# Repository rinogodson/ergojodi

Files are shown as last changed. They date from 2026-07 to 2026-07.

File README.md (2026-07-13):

ergojodi logo

---
### Fully custom hot-swappable split mechanical keyboard that features a very ergonomic layout and uses USB-C for everything, way better than accident-friendly TRRS. Runs on QMK software, controlling key functions. The fully assembled keyboard's 3D Model's STEP file is over 100MB, So, you can find the drive link in `assembly.md`
The name comes from two words, "Ergo" meaning Ergonomics, and "Jodi" meaning pair.

> **Why I built this**: I needed an ergonomic keyboard to use with my machines that suits my ergonomics. I aligned and laid out the keys to match my finger heights.

gray_run_8fps

ergojodi assembled

---

### Schematic
Ergogen keebs doesn't need a schematic, because it is in ergogen... But, for your sake, I made one!

Schematic

---
### PCB
Designed in Ergogen and Routed in KiCad

PCB

3D PCB

---
## Case  
Case designed with ergogen. It comes in two parts: the top plate and bottom case. The M2 Screw holes are already present, and heat inserts should be added to the top plate.

case

---
## Firmware  
This Keyboard runs on QMK software; the uf2 file to flash can be found in `firmware/uf2`.  

## Parts List and Links:
| Name | Price (USD) | Quantity | Link | Total (USD) | Delivery and Tax | Shop Total (USD) |
| :--- | :--- | :--- | :--- | :--- | :--- | :--- |
| Outemu Mechanical Switches for Swappable Keyboards (Pack of 20) | $2.30 | 2 | [Visit Shop](https://www.thecosmicbyte.com/product/outemu-mechanical-switches-for-swappable-keyboards-pack-of-20/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) | $4.60 | $0.87 | $5.46 |
| Gateron Hotswap Sockets | $0.10 | 40 | [Visit Shop](https://stackskb.com/store/gateron-hotswap-sockets/) | $4.18 | $1.36 | $5.54 |
| Blank DSA Keycaps (1u) (5n per order) | $0.99 | 8 | [Visit Shop](https://meckeys.com/shop/accessories/keyboard-accessories/keycaps/blank/blank-dsa-keycaps-1u/) | $7.94 | $1.04 | $8.98 |
| TYPE-C-31-M-12-Hroparts-5A 1 16P Female Type-C SMD USB Connectors ROHS | $0.40 | 2 | [Visit Shop](https://robu.in/product/type-c-31-m-12-hroparts-5a-1-16p-female-type-c-smd-usb-connectors-rohs/) | $0.79 | Free | $14.33 |
| Seeed Studio XIAO RP2040 v1.0 | $6.46 | 2 | [Visit Shop](https://robu.in/product/seeed-studio-xiao-rp2040-v1-0/) | $12.91 | | |
| 1N4148-T50A-Onsemi-100V 1V@10mA 4ns 200mA DO-35 Switching Diodes ROHS | $0.06 | 10 | [Visit Shop](https://robu.in/product/1n4148-t50a-onsemi-100v-1v10ma-4ns-200ma-do-35-switching-diodes-rohs/) | $0.63 | | |
| M2 X 3mm Brass Threaded Inserts (Dia. 2mm, Length 3mm) | $0.02 | 15 | [Visit Shop](https://onlyscrews.in/products/m2-x-3mm-brass-threaded-inserts?variant=49728872448313) | $0.28 | $0.73 | $1.70 |
| M2 X 8mm Phillips Round head Laptop Screw (Dia. 2mm, Length 8mm) | $0.05 | 15 | [Visit Shop](https://onlyscrews.in/products/m2-x-8mm-phillips-round-head-laptop-screw-1?variant=49693360423225) | $0.69 | | |
| PCB Manufacturing & Shipping (JLCPCB) | $26.17 | 1 | [Visit Shop](https://jlcpcb.com/) | $26.17 | - | $26.17 |
| 3D Printing & Shipping (3Ding) | $11.43 | 1 | [Visit Shop](https://3ding.in/) | $11.43 | - | $11.43 |

### Total ~ $74

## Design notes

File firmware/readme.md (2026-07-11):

# ergojodi

ergojodi

*A short description of the keyboard/project*

* Keyboard Maintainer: [Rino Godson](https://github.com/rinogodson)
* Hardware Supported: *The PCBs, controllers supported*
* Hardware Availability: *Links to where you can find this hardware*

Make example for this keyboard (after setting up your build environment):

    make ergojodi:default

Flashing example for this keyboard:

    make ergojodi:default:flash

See the [build environment setup](https://docs.qmk.fm/#/getting_started_build_tools) and the [make instructions](https://docs.qmk.fm/#/getting_started_make_guide) for more information. Brand new to QMK? Start with our [Complete Newbs Guide](https://docs.qmk.fm/#/newbs).

## Bootloader

Enter the bootloader in 3 ways:

* **Bootmagic reset**: Hold down the key at (0,0) in the matrix (usually the top left key or Escape) and plug in the keyboard
* **Physical reset button**: Briefly press the button on the back of the PCB - some may have pads you must short instead
* **Keycode in layout**: Press the key mapped to `QK_BOOT` if it is available

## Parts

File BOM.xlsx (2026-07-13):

Name | Price | Quantity | Link | Total | Delivery and Tax | Shop Total
Outemu Mechanical Switches for Swappable Keyboards (Pack of 20) | ₹220.00 | 2 | https://www.thecosmicbyte.com/product/outemu-mechanical-switches-for-swappable-keyboards-pack-of-20/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 | ₹440.00 | ₹83.00 | ₹523.00
Gateron Hotswap Sockets | ₹10.00 | 40 | https://stackskb.com/store/gateron-hotswap-sockets/ | ₹400.00 | ₹130.00 | ₹530.00
Blank DSA Keycaps (1u) (5n per order) | ₹95.00 | 8 | https://meckeys.com/shop/accessories/keyboard-accessories/keycaps/blank/blank-dsa-keycaps-1u/ | ₹760.00 | ₹100.00 | ₹860.00
TYPE-C-31-M-12-Hroparts-5A 1 16P Female Type-C SMD USB Connectors ROHS | ₹38.00 | 2 | https://robu.in/product/type-c-31-m-12-hroparts-5a-1-16p-female-type-c-smd-usb-connectors-rohs/ | ₹76.00 | Free | ₹1372.00
Seeed Studio XIAO RP2040 v1.0 | ₹618.00 | 2 | https://robu.in/product/seeed-studio-xiao-rp2040-v1-0/ | ₹1236.00
1N4148-T50A-Onsemi-100V 1V@10mA 4ns 200mA DO-35 Switching Diodes ROHS | ₹6.00 | 10 | https://robu.in/product/1n4148-t50a-onsemi-100v-1v10ma-4ns-200ma-do-35-switching-diodes-rohs/ | ₹60.00
M2 X 3mm Brass Threaded Inserts (Dia. 2mm, Length 3mm) | ₹1.80 | 15 | https://onlyscrews.in/products/m2-x-3mm-brass-threaded-inserts?variant=49728872448313 | ₹27.00 | ₹70.00 | ₹163.00
M2 X 8mm Phillips Round head Laptop Screw (Dia. 2mm, Length 8mm) | ₹4.40 | 15 | https://onlyscrews.in/products/m2-x-8mm-phillips-round-head-laptop-screw-1?variant=49693360423225 | ₹66.00
PCB Manufacturing & Shipping (JLCPCB) | $26.17 | 1 | https://jlcpcb.com/ | $26.17 | - | $26.17
3D Printing & Shipping (3Ding) | ₹1094.00 | 1 | https://3ding.in/ | ₹1094.00 | - | ₹1094.00
 |  |  |  |  | Total (USD): | $73.62
 |  |  |  |  | Total (INR): | ₹ 7,046.70

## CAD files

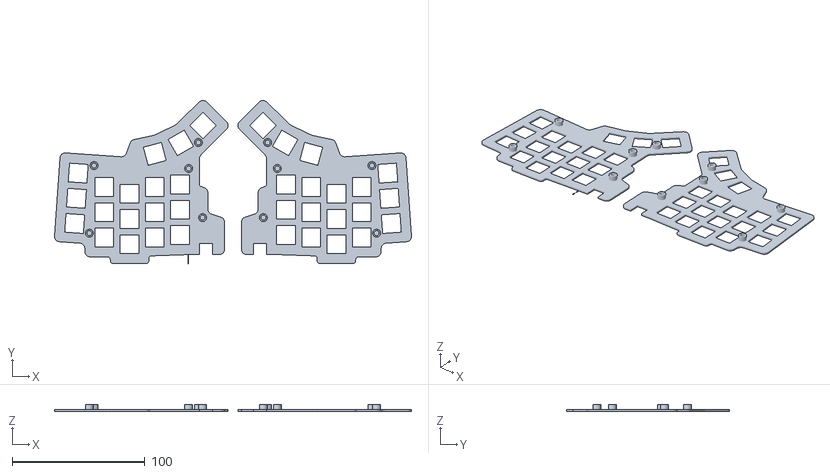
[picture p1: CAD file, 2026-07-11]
cases/top_new.stl
268.6 x 122.7 x 5.10

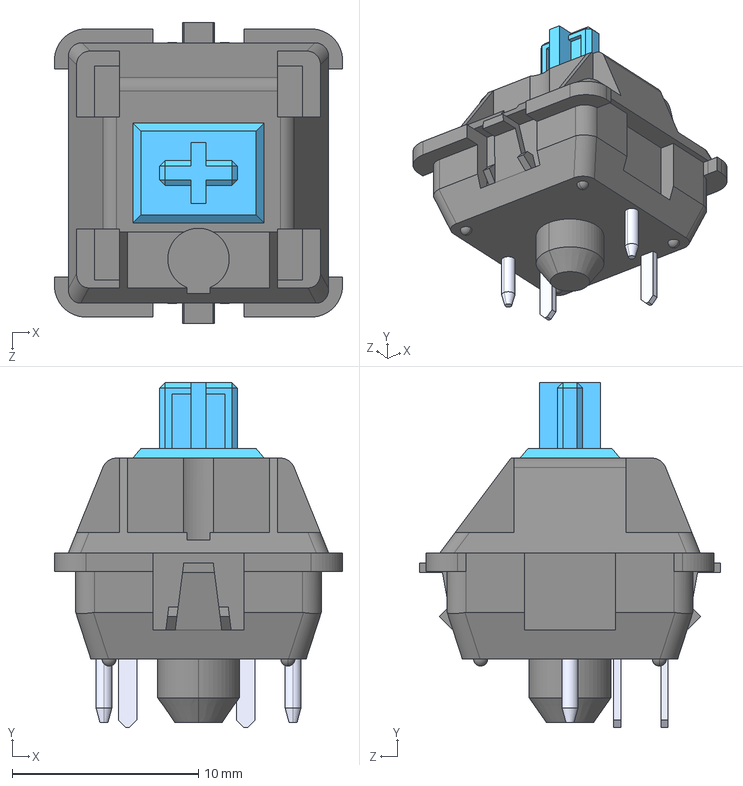
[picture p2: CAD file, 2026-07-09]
pcbs/models/mx.step
15.5 x 18.5 x 16.2 mm

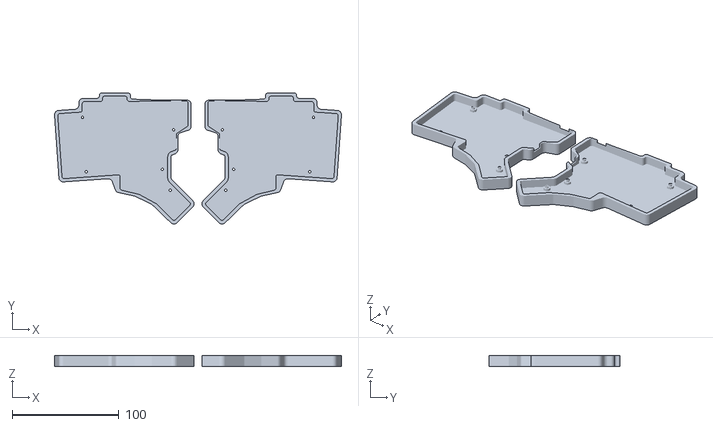
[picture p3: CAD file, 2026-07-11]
cases/bottom_new.stl
268.6 x 122.7 x 10.2

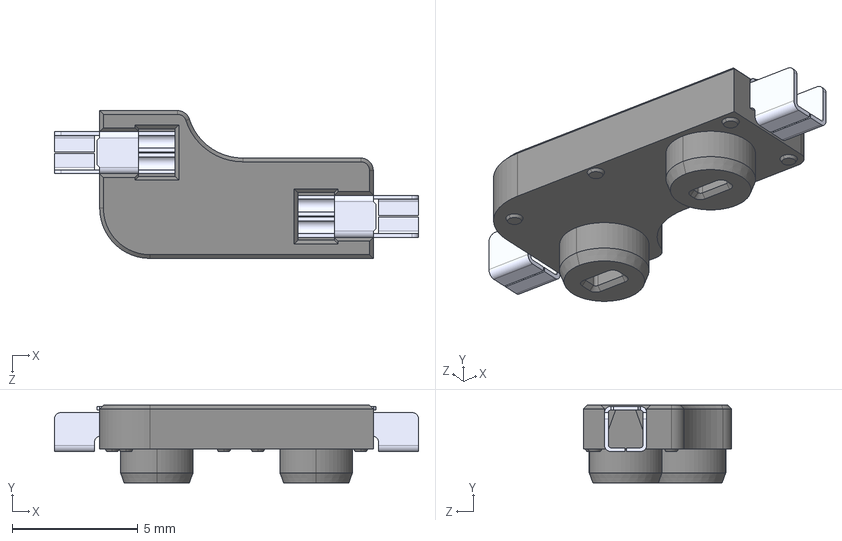
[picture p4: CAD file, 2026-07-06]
pcbs/models/kailh.step
14.5 x 3.10 x 5.89 mm

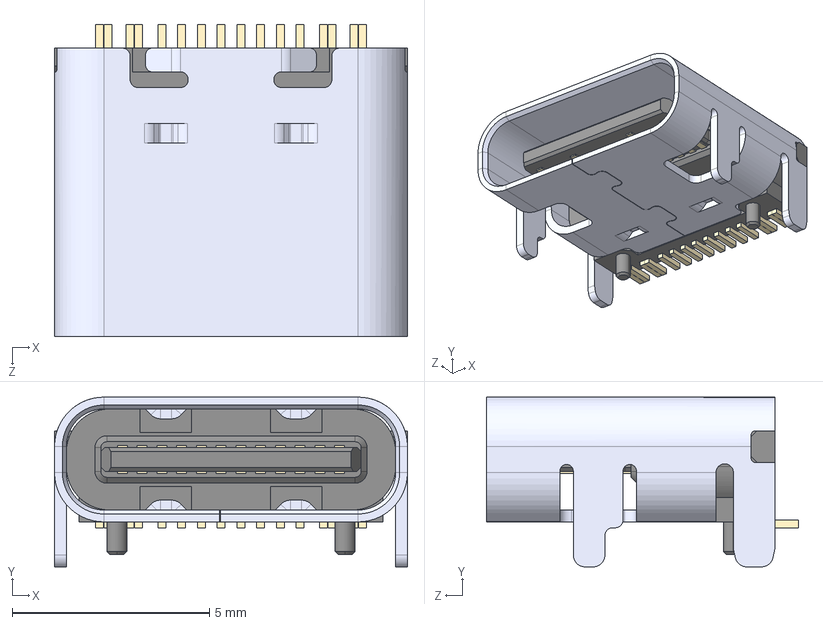
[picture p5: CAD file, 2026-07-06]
pcbs/models/usb.step
8.94 x 4.30 x 7.90 mm

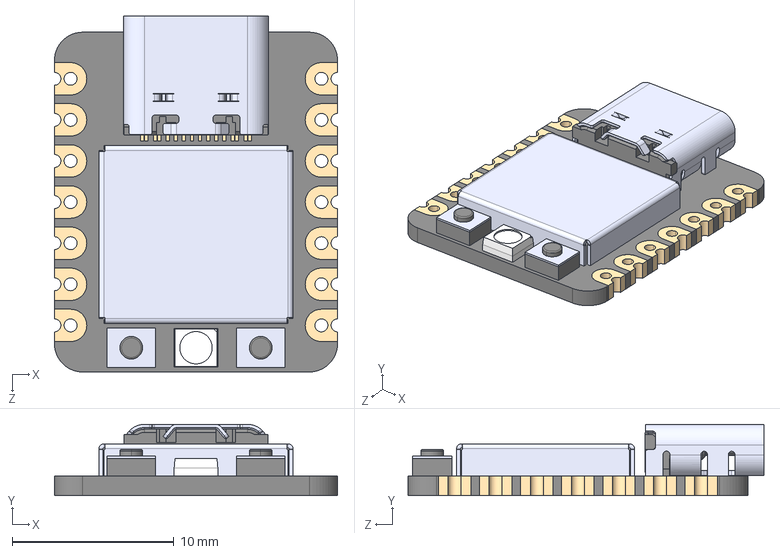
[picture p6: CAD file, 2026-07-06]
pcbs/models/xiao.step
17.5 x 4.40 x 22.0 mm

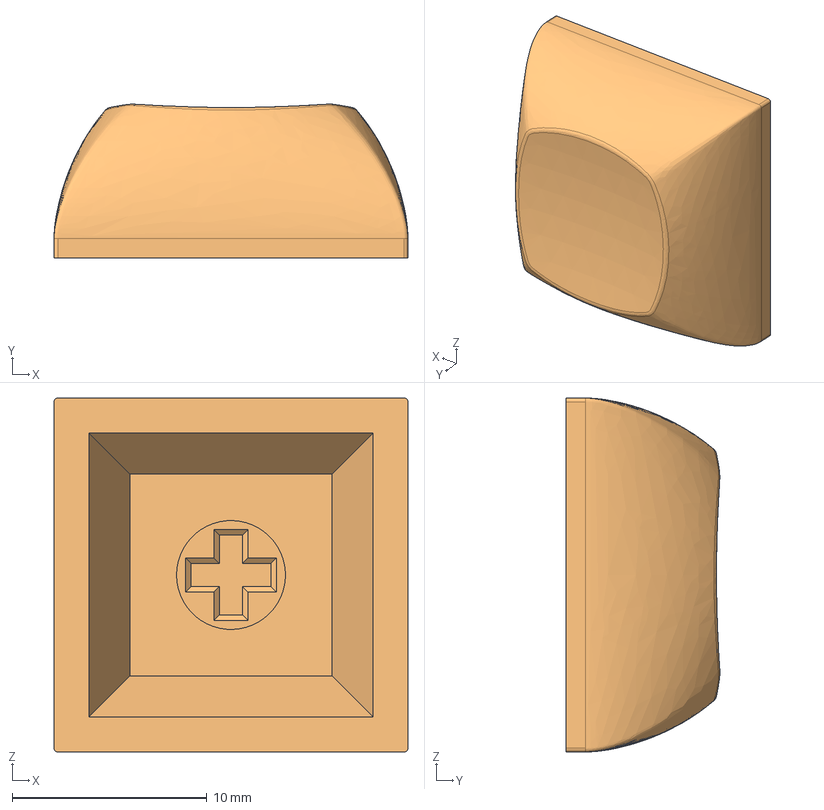
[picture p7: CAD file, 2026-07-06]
pcbs/models/dsa.step
18.2 x 7.91 x 18.2 mm

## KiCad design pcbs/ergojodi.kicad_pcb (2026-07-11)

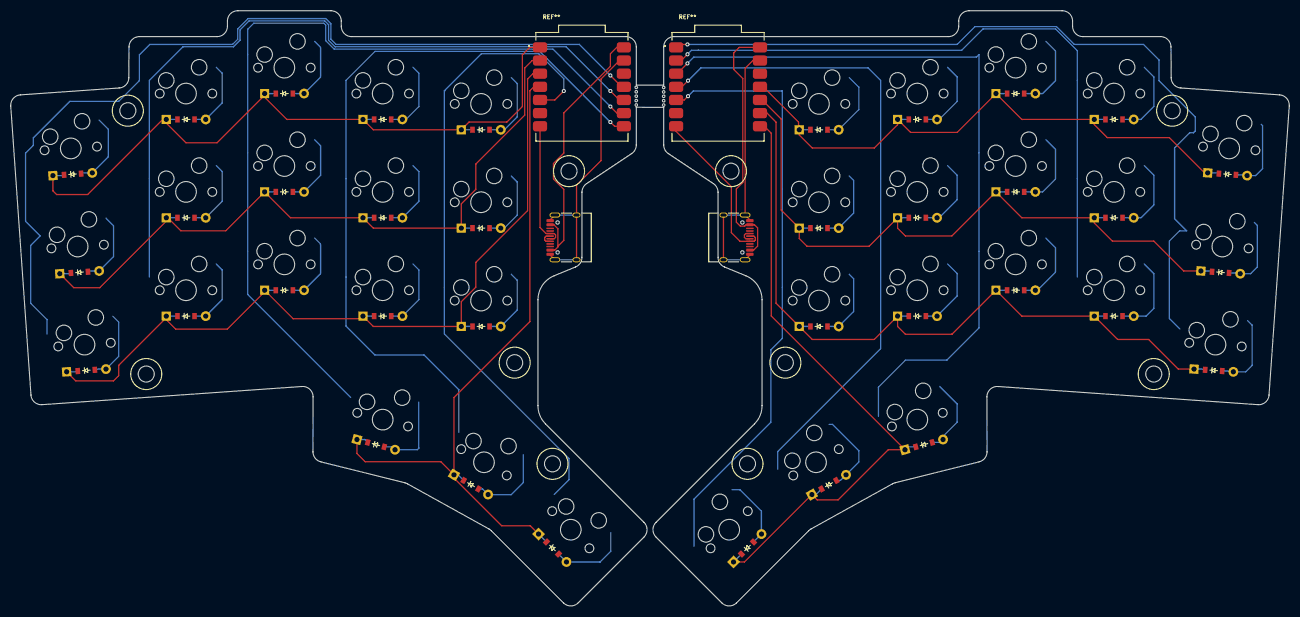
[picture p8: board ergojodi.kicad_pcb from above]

Board: 2 copper layers, 247.0 x 115.0 mm, 74 parts (0 on the bottom side), 62 nets.

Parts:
D1, D2, D3, D4, D5, D6, D7, D8, D9, D10, D11, D12, D13, D14, D15, D16, D17, D18, D19, D20, D21, D22, D23, D24, D25, D26, D27, D28, D29, D30, D31, D32, D33, D34, D35, D36: ComboDiode
S1, S2, S3, S4, S5, S6, S7, S8, S9, S10, S11, S12, S13, S14, S15, S16, S17, S18, S19, S20, S21, S22, S23, S24, S25, S26, S27, S28, S29, S30, S31, S32, S33, S34, S35, S36: MX
XX2, XX3: USB_C_Receptacle_HRO_TYPE-C-31-M-12

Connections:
far_thumb: D18.2, S18.2
home_thumb: D17.2, S17.2
index_bottom: D10.2, S10.2
index_home: D11.2, S11.2
index_top: D12.2, S12.2
inner_bottom: D13.2, S13.2
inner_home: D14.2, S14.2
inner_top: D15.2, S15.2
l_A0: D3.1, D6.1, D9.1, D12.1, D15.1
l_A1: D2.1, D5.1, D8.1, D11.1, D14.1
l_A2: D1.1, D4.1, D7.1, D10.1, D13.1
l_A3: D16.1, D17.1, D18.1
l_A4: S13.1, S14.1, S15.1, S18.1
l_A7: S10.1, S11.1, S12.1, S17.1
l_A8: S7.1, S8.1, S9.1, S16.1
l_A9: S4.1, S5.1, S6.1
l_A10: S1.1, S2.1, S3.1
l_Dminus: XX2.A7, XX2.B7
l_Dplus: XX2.A6, XX2.B6
l_GND: XX2.A1, XX2.A12, XX2.B1, XX2.B12, XX2.NP
l_VCC: XX2.A4, XX2.A9, XX2.B4, XX2.B9
middle_bottom: D7.2, S7.2
middle_home: D8.2, S8.2
middle_top: D9.2, S9.2
mirror_far_thumb: D36.2, S36.2
mirror_home_thumb: D35.2, S35.2
mirror_index_bottom: D28.2, S28.2
mirror_index_home: D29.2, S29.2
mirror_index_top: D30.2, S30.2
mirror_inner_bottom: D31.2, S31.2
mirror_inner_home: D32.2, S32.2
mirror_inner_top: D33.2, S33.2
mirror_middle_bottom: D25.2, S25.2
mirror_middle_home: D26.2, S26.2
mirror_middle_top: D27.2, S27.2
mirror_near_thumb: D34.2, S34.2
mirror_pinky_bottom: D19.2, S19.2
mirror_pinky_home: D20.2, S20.2
mirror_pinky_top: D21.2, S21.2
mirror_ring_bottom: D22.2, S22.2
mirror_ring_home: D23.2, S23.2
mirror_ring_top: D24.2, S24.2
near_thumb: D16.2, S16.2
pinky_bottom: D1.2, S1.2
pinky_home: D2.2, S2.2
pinky_top: D3.2, S3.2
r_A0: S19.1, S20.1, S21.1
r_A1: S22.1, S23.1, S24.1
r_A2: S25.1, S26.1, S27.1, S34.1
r_A3: S28.1, S29.1, S30.1, S35.1
r_A4: S31.1, S32.1, S33.1, S36.1
r_A7: D34.1, D35.1, D36.1
r_A8: D19.1, D22.1, D25.1, D28.1, D31.1
r_A9: D20.1, D23.1, D26.1, D29.1, D32.1
r_A10: D21.1, D24.1, D27.1, D30.1, D33.1
r_Dminus: XX3.A7, XX3.B7
r_Dplus: XX3.A6, XX3.B6
r_GND: XX3.A1, XX3.A12, XX3.B1, XX3.B12, XX3.NP
r_VCC: XX3.A4, XX3.A9, XX3.B4, XX3.B9
ring_bottom: D4.2, S4.2
ring_home: D5.2, S5.2
ring_top: D6.2, S6.2

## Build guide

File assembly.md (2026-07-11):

The Assembly 3D file is available on this link (can't push to github as it is 116MB):
https://drive.google.com/file/d/1jncvAFzqwWMEMiQR0Tw-UXtgj0F9NIJO/view?usp=sharing

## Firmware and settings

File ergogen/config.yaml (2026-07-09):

units:
  mcu_w: 15
  mcu_h: 20
  mcu_p: 2

  m2_ext: 6/2
  m2_ext_height: 2
  m2_ext_hole: 2.3/2
  m2_recess: 1.5
  m2_recess_radius: 4.5/2
  m2_boss: 3/2
  m2_boss_height: 1.4
  m2_hol: ((m2_boss*2)+0.1)/2

  m2_heat: 3.9/2
  m2_depth: 4

  # trrs_w: 13
  # (3-1.8)+2+1.6+4
  wall_thick_original: 3
  wall_thick: wall_thick_original*2
  pcb_thick: 1.6
  p: u+3
  p_in: p+1
  p_outer: p_in+wall_thick
  top_thick: 1.4
  x_height: wall_thick_original+m2_ext_height+pcb_thick+5-top_thick # 3+3+1.6+5-1.4
  k: 14
  k_t: k+0.075

points:
  zones:
    matrix:
      rows:
        bottom:
          # ROW3
          row_net: l_A2
          mirror.row_net: r_A8
        home:
          # ROW2
          row_net: l_A1
          mirror.row_net: r_A9
        top:
          # ROW1
          row_net: l_A0
          mirror.row_net: r_A10
      columns:
        pinky:
          # COL1
          key:
            column_net: l_A10
            mirror.column_net: r_A0
        ring:
          # COL2
          key:
            column_net: l_A9
            mirror.column_net: r_A1
            origin: [-12, -u]
            stagger: 10
            splay: -4
        middle:
          # COL3
          key:
            column_net: l_A8
            mirror.column_net: r_A2
            stagger: 5
        index:
          # COL4
          key:
            column_net: l_A7
            mirror.column_net: r_A3
            stagger: -5
        inner:
          # COL5
          key:
            column_net: l_A4
            mirror.column_net: r_A4
            stagger: -2
      anchor:
        shift: [100, -150]
        rotate: 4
    thumbfan:
      anchor:
        ref: matrix_index_bottom
        shift: [0, -25]
        rotate: -15
      columns:
        near:
          #COL3
          key:
            column_net: l_A8
            mirror.column_net: r_A2
        home:
          #COL4
          key:
            column_net: l_A7
            mirror.column_net: r_A3
            spread: U
            splay: -15
            origin: [-10, -9]
        far:
          #COL5
          key:
            column_net: l_A4
            mirror.column_net: r_A4
            spread: U
            splay: -15
            origin: [-10, -9]
      rows:
        thumb:
          #ROW4
          row_net: l_A3
          mirror.row_net: r_A7
  rotate: 0
  mirror: &mirror
    ref: thumbfan_far_thumb
    distance: 45
outlines:
  usb_cutout:
    - what: rectangle
      size: [9.5, 4]
      operation: add
      where:
        ref: matrix_inner_home
        shift: [20, -3.4mcu_p]
        rotate: 90
    - what: rectangle
      size: [9.5, 4]
      operation: add
      where:
        ref: mirror_matrix_inner_home
        shift: [20, -3.4mcu_p]
        rotate: 90
  keys:
    - what: rectangle
      where: true
      size: [k, k]
  keys_cutout:
    - what: rectangle
      where: true
      size: [k_t, k_t]
  m2_silk:
    - what: circle
      where:
        ref: matrix_pinky_top
        shift: [0.5p+0.5, 0.5p-4.5]
        rotate: 0
      radius: m2_ext
      operation: add
    - what: circle
      where:
        ref: matrix_pinky_bottom
        shift: [0.5p+0.5, -0.5p+4.5]
        rotate: 0
      radius: m2_ext
      operation: add
    - what: circle
      where:
        ref: matrix_inner_bottom
        shift: [0.5p-4.5, -0.5p-1]
        rotate: 0
      radius: m2_ext
      operation: add
    - what: circle
      where:
        ref: matrix_inner_home
        shift: [0.5p+6, 0.5p-5]
        rotate: 0
      radius: m2_ext
      operation: add
    - what: circle
      where:
        ref: thumbfan_far_thumb
        shift: [-0.5p-0.5, 0.5p-4.5]
        rotate: 0
      radius: m2_ext
      operation: add
      # right
    - what: circle
      where:
        ref: mirror_matrix_pinky_top
        shift: [0.5p+0.5, 0.5p-4.5]
        rotate: 0
      radius: m2_ext
      operation: add
    - what: circle
      where:
        ref: mirror_matrix_pinky_bottom
        shift: [0.5p+0.5, -0.5p+4.5]
        rotate: 0
      radius: m2_ext
      operation: add
    - what: circle
      where:
        ref: mirror_matrix_inner_bottom
        shift: [0.5p-4.5, -0.5p-1]
        rotate: 0
      radius: m2_ext
      operation: add
    - what: circle
      where:
        ref: mirror_matrix_inner_home
        shift: [0.5p+6, 0.5p-5]
        rotate: 0
      radius: m2_ext
      operation: add
    - what: circle
      where:
        ref: mirror_thumbfan_far_thumb
        shift: [-0.5p-0.5, 0.5p-4.5]
        rotate: 0
      radius: m2_ext
      operation: add
  m2_top_hole:
    - what: circle
      where:
        ref: matrix_pinky_top
        shift: [0.5p+0.5, 0.5p-4.5]
        rotate: 0
      radius: m2_heat
      operation: add
    - what: circle
      where:
        ref: matrix_pinky_bottom
        shift: [0.5p+0.5, -0.5p+4.5]
        rotate: 0
      radius: m2_heat
      operation: add
    - what: circle
      where:
        ref: matrix_inner_bottom
        shift: [0.5p-4.5, -0.5p-1]
        rotate: 0
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

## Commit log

2026-07-04 initialized PCB and better and more compact layout...
2026-07-06 added 3D models and added screws, and tried to make the case
    [dsa.step, kailh.step, mx.step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]
2026-07-07 m2 sizes added, making case
    [caseoriginal.jscad.stl]
2026-07-07 made the case, now need to copy all over to the left side
2026-07-09 made the entire case, top plate screw holes, and USB cutouts
    [caseoriginal.jscad.stl]
2026-07-09 pcb files add
    [dsa.step, ergojodi.kicad_pcb, kailh.step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]
2026-07-11 Routed the PCB
    [ergojodi.kicad_pcb]
2026-07-11 added gerber files
2026-07-11 pcbs folder migrate
    [dsa.step, ergojodi.kicad_pcb, kailh.step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]
2026-07-11 added cases (STL)
    [bottom_new.stl, top_new.stl]
2026-07-11 added the pcb.step
2026-07-11 added the assembly 3d model markdown file
2026-07-11 flipped the top plate to match 3D printing
    [top_new.stl]
2026-07-11 Add ErgoJodi keyboard details to README
    Added detailed information about the ErgoJodi keyboard, including its features, schematic, PCB design, case details, firmware, and parts list.
2026-07-11 Update README with 3D Model file information
    Added information about the keyboard's 3D Model's STEP file location in assembly.md.
